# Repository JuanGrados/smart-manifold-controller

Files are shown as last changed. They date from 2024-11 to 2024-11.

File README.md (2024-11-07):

# smart-manifold-controller

__Documentation in progress....__

This is a repository for a smart manifold controller.
It is a porject to control 4 electric water valves and measure the water flow of each of them with water flow sensors.

The project is build around the ESP32-C3-Mini and it is programmed using ESPHome.

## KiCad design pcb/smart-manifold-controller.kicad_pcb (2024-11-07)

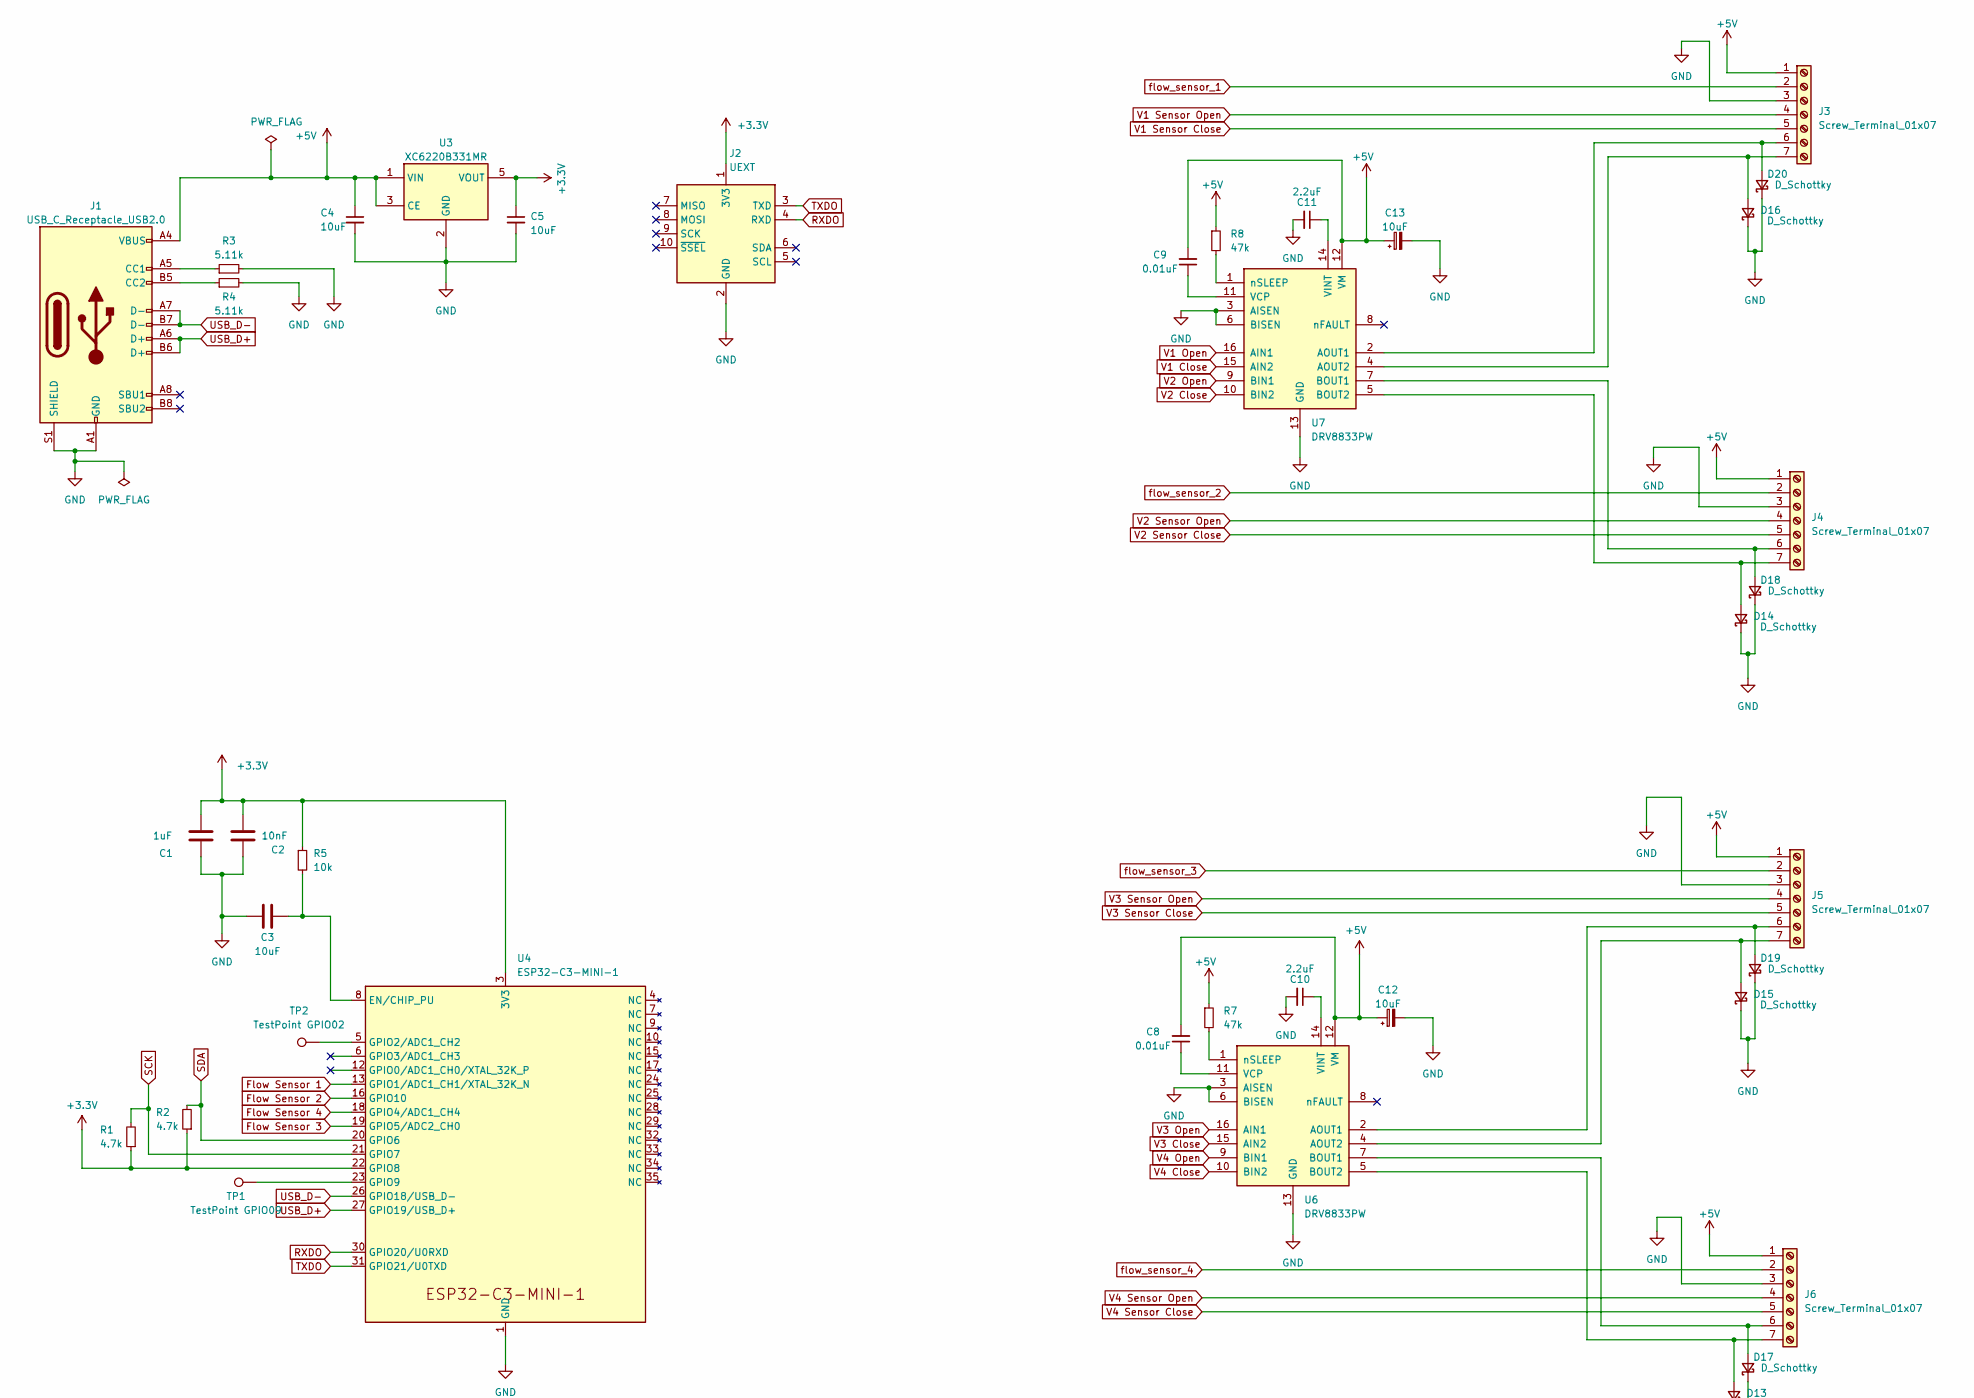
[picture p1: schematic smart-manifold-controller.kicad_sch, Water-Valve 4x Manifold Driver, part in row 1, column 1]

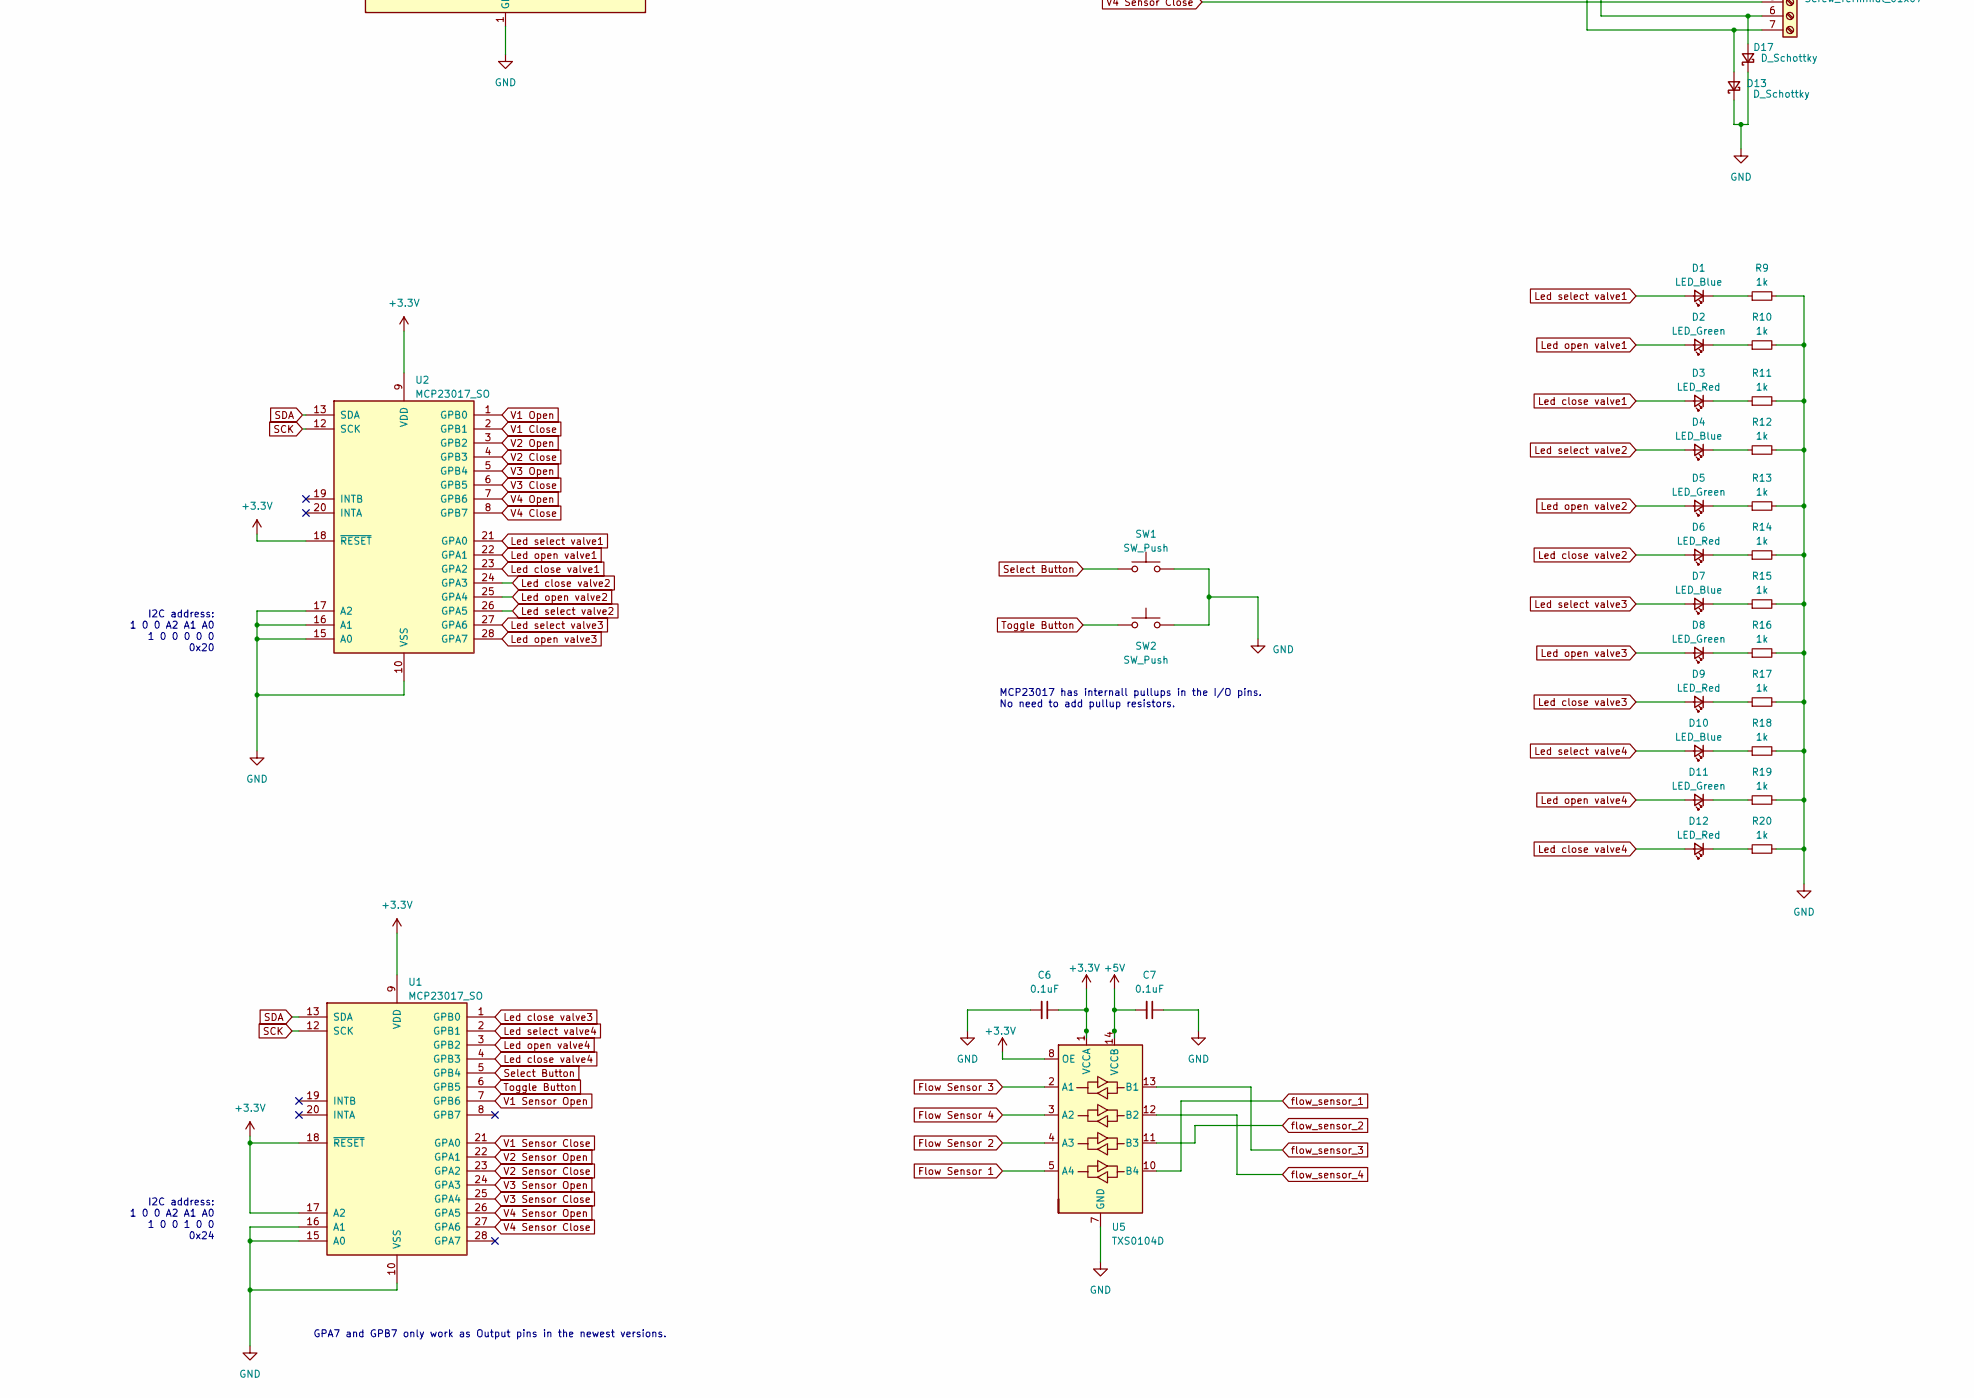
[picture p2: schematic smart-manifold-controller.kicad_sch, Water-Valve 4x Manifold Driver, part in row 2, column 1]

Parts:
C1: 1uF; C_0603_1608Metric
C2: 10nF; C_0603_1608Metric
C3, C4, C5, C12, C13: 10uF; C_0603_1608Metric
C6, C7: 0.1uF; C_0603_1608Metric
C8, C9: 0.01uF; C_0603_1608Metric
C10, C11: 2.2uF; C_0603_1608Metric
D1, D4, D7, D10: LED_Blue; LED_1206_3216Metric
D2, D5, D8, D11: LED_Green; LED_1206_3216Metric
D3, D6, D9, D12: LED_Red; LED_1206_3216Metric
D13, D14, D15, D16, D17, D18, D19, D20: D_Schottky; D_0603_1608Metric
J1: USB_C_Receptacle_USB2.0; USB_C_Receptacle_HRO_TYPE-C-31-M-12
J2: UEXT; JST_EH_S4B-EH_1x04_P2.50mm_Horizontal
J3, J4, J5, J6: Screw_Terminal_01x07; TerminalBlock_Phoenix_MKDS-1,5-7-5.08_1x07_P5.08mm_Horizont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
R1, R2: 4.7k; R_0603_1608Metric
R3, R4: 5.11k; R_0603_1608Metric
R5: 10k; R_0603_1608Metric
R7, R8: 47k; R_0603_1608Metric
R9, R10, R11, R12, R13, R14, R15, R16, R17, R18, R19, R20: 1k; R_0603_1608Metric
SW1, SW2: SW_Push; SW_Push_1P1T_NO_6x6mm_H9.5mm
TP1: TestPoint GPIO09; TestPoint_Pad_D2.0mm
TP2: TestPoint GPIO02; TestPoint_Pad_D2.0mm
U1, U2: MCP23017_SO; SOIC-28W_7.5x17.9mm_P1.27mm
U3: XC6220B331MR; SOT-23-5
U4: ESP32-C3-MINI-1
U5: TXS0104D; SOIC-14_3.9x8.7mm_P1.27mm
U6, U7: DRV8833PW; TSSOP-16_4.4x5mm_P0.65mm

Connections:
+3.3V: C1.1, C2.1, C5.1, C6.1, J2.1 (3V3), R1.1, R2.1, R5.1, U1.9 (VDD), U1.17 (A2), U1.18 (~RESET), U2.9 (VDD), U2.18 (~RESET), U3.5 (VOUT), U4.3 (3V3), U4.22 (GPIO8), U5.1 (VCCA), U5.8 (OE)
+5V: C4.1, C7.2, C8.2, C9.2, C12.1, C13.1, J1.A4 (VBUS), J1.A9 (VBUS), J1.B4 (VBUS), J1.B9 (VBUS), J3.1, J4.1, J5.1, J6.1, R7.1, R8.1, U3.1 (VIN), U3.3 (CE), U5.14 (VCCB), U6.12 (VM), U7.12 (VM)
Flow Sensor 1: U4.13 (GPIO1/ADC1_CH1/XTAL_32K_N), U5.5 (A4)
Flow Sensor 2: U4.16 (GPIO10), U5.4 (A3)
Flow Sensor 3: U4.19 (GPIO5/ADC2_CH0), U5.2 (A1)
Flow Sensor 4: U4.18 (GPIO4/ADC1_CH4), U5.3 (A2)
GND: C1.2, C2.2, C3.1, C4.2, C5.2, C6.2, C7.1, C10.2, C11.2, C12.2, C13.2, D13.1 (K), D14.1 (K), D15.1 (K), D16.1 (K), D17.1 (K), D18.1 (K), D19.1 (K), D20.1 (K), J1.A1 (GND), J1.A12 (GND), J1.B1 (GND), J1.B12 (GND), J1.S1 (SHIELD), J2.2 (GND), J3.3, J4.3, J5.3, J6.3, R3.2, R4.2, R9.2, R10.2, R11.2, R12.2, R13.2, R14.2, R15.2, R16.2, R17.2, R18.2, R19.2, R20.2, SW1.2, SW2.2, U1.10 (VSS), U1.15 (A0), U1.16 (A1), U2.10 (VSS), U2.15 (A0), U2.16 (A1), U2.17 (A2), U3.2 (GND), U4.1 (GND), U4.2 (GND), U4.11 (GND), U4.14 (GND), U4.36 (GND), U4.37 (GND), U4.38 (GND), U4.39 (GND), U4.40 (GND), U4.41 (GND), U4.42 (GND), U4.43 (GND), U4.44 (GND), U4.45 (GND), U4.46 (GND), U4.47 (GND), U4.48 (GND), U4.49 (GND), U4.50 (GND), U4.51 (GND), U4.52 (GND), U4.53 (GND), U5.7 (GND), U6.3 (AISEN), U6.6 (BISEN), U6.13 (GND), U7.3 (AISEN), U7.6 (BISEN), U7.13 (GND)
Led close valve1: D3.2 (A), U2.23 (GPA2)
Led close valve2: D6.2 (A), U2.24 (GPA3)
Led close valve3: D9.2 (A), U1.1 (GPB0)
Led close valve4: D12.2 (A), U1.4 (GPB3)
Led open valve1: D2.2 (A), U2.22 (GPA1)
Led open valve2: D5.2 (A), U2.25 (GPA4)
Led open valve3: D8.2 (A), U2.28 (GPA7)
Led open valve4: D11.2 (A), U1.3 (GPB2)
Led select valve1: D1.2 (A), U2.21 (GPA0)
Led select valve2: D4.2 (A), U2.26 (GPA5)
Led select valve3: D7.2 (A), U2.27 (GPA6)
Led select valve4: D10.2 (A), U1.2 (GPB1)
unnamed: D1.1 (K), R9.1
unnamed: D2.1 (K), R10.1
unnamed: D3.1 (K), R11.1
unnamed: D4.1 (K), R12.1
unnamed: D5.1 (K), R13.1
unnamed: D6.1 (K), R14.1
unnamed: D7.1 (K), R15.1
unnamed: D8.1 (K), R16.1
unnamed: D9.1 (K), R17.1
unnamed: D10.1 (K), R18.1
unnamed: D11.1 (K), R19.1
unnamed: D12.1 (K), R20.1
unnamed: D13.2 (A), J6.7, U6.5 (BOUT2)
unnamed: D14.2 (A), J4.7, U7.5 (BOUT2)
unnamed: D15.2 (A), J5.7, U6.4 (AOUT2)
unnamed: D16.2 (A), J3.7, U7.4 (AOUT2)
unnamed: D17.2 (A), J6.6, U6.7 (BOUT1)
unnamed: D18.2 (A), J4.6, U7.7 (BOUT1)
unnamed: D19.2 (A), J5.6, U6.2 (AOUT1)
unnamed: D20.2 (A), J3.6, U7.2 (AOUT1)
unnamed: J1.A5 (CC1), R3.1
unnamed: J1.B5 (CC2), R4.1
unnamed: C3.2, R5.2, U4.8 (EN/CHIP_PU)
unnamed: TP2.1, U4.5 (GPIO2/ADC1_CH2)
unnamed: TP1.1, U4.23 (GPIO9)
unnamed: C8.1, U6.11 (VCP)
unnamed: C10.1, U6.14 (VINT)
unnamed: R7.2, U6.1 (nSLEEP)
unnamed: C9.1, U7.11 (VCP)
unnamed: C11.1, U7.14 (VINT)
unnamed: R8.2, U7.1 (nSLEEP)
RXDO: J2.4 (RXD), U4.30 (GPIO20/U0RXD)
SCK: R1.2, U1.12 (SCK), U2.12 (SCK), U4.21 (GPIO7)
SDA: R2.2, U1.13 (SDA), U2.13 (SDA), U4.20 (GPIO6)
Select Button: SW1.1, U1.5 (GPB4)
TXDO: J2.3 (TXD), U4.31 (GPIO21/U0TXD)
Toggle Button: SW2.1, U1.6 (GPB5)
USB_D+: J1.A6 (D+), J1.B6 (D+), U4.27 (GPIO19/USB_D+)
USB_D-: J1.A7 (D-), J1.B7 (D-), U4.26 (GPIO18/USB_D-)
V1 Close: U2.2 (GPB1), U7.15 (AIN2)
V1 Open: U2.1 (GPB0), U7.16 (AIN1)
V1 Sensor Close: J3.5, U1.21 (GPA0)
V1 Sensor Open: J3.4, U1.7 (GPB6)
V2 Close: U2.4 (GPB3), U7.10 (BIN2)
V2 Open: U2.3 (GPB2), U7.9 (BIN1)
V2 Sensor Close: J4.5, U1.23 (GPA2)
V2 Sensor Open: J4.4, U1.22 (GPA1)
V3 Close: U2.6 (GPB5), U6.15 (AIN2)
V3 Open: U2.5 (GPB4), U6.16 (AIN1)
V3 Sensor Close: J5.5, U1.25 (GPA4)
V3 Sensor Open: J5.4, U1.24 (GPA3)
V4 Close: U2.8 (GPB7), U6.10 (BIN2)
V4 Open: U2.7 (GPB6), U6.9 (BIN1)
V4 Sensor Close: J6.5, U1.27 (GPA6)
V4 Sensor Open: J6.4, U1.26 (GPA5)
flow_sensor_1: J3.2, U5.10 (B4)
flow_sensor_2: J4.2, U5.11 (B3)
flow_sensor_3: J5.2, U5.13 (B1)
flow_sensor_4: J6.2, U5.12 (B2)

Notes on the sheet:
GPA7 and GPB7 only work as Output pins in the newest versions.
I2C address: 1 0 0 A2 A1 A0 1 0 0 0 0 0 0x20
I2C address: 1 0 0 A2 A1 A0 1 0 0 1 0 0 0x24
MCP23017 has internall pullups in the I/O pins. No need to add pullup resistors.

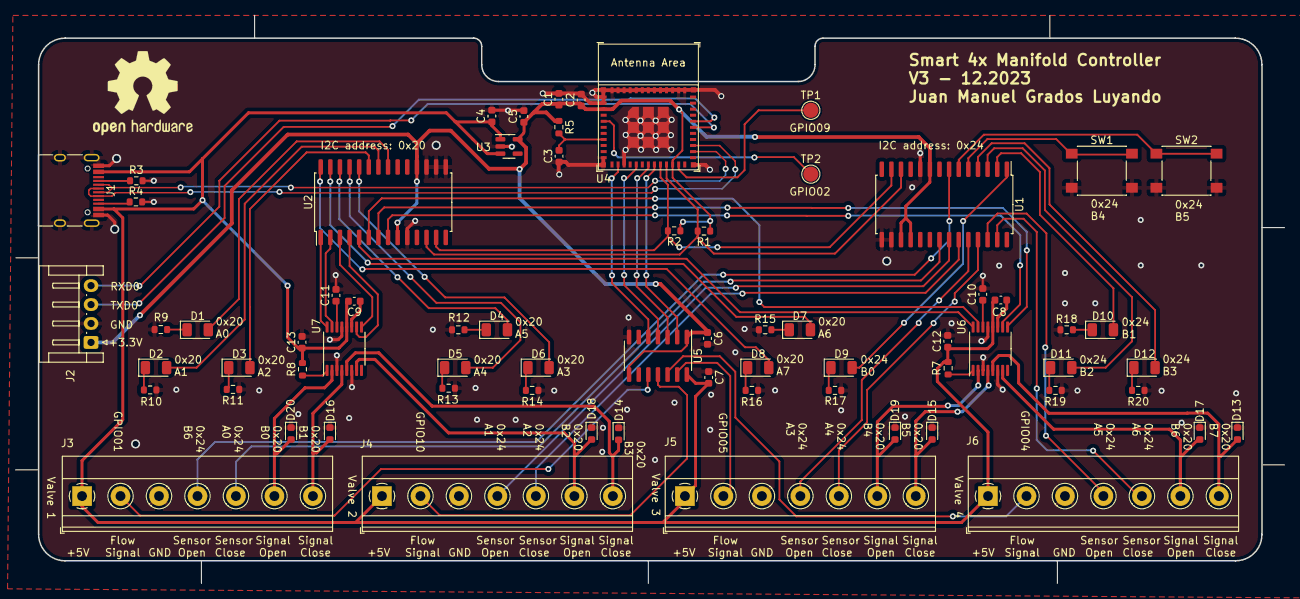
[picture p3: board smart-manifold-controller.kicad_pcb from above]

Board: 2 copper layers, 167.6 x 75.0 mm, 69 parts (0 on the bottom side), 78 nets.

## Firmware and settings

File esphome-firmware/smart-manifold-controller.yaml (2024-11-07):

esphome:
  name: smart-manifold-controller
  friendly_name: smart-manifold-controller

esp32:
  board: esp32-c3-devkitm-1
  framework:
    type: arduino

# Enable logging
logger:

# Enable Home Assistant API
api:
  encryption:
    key: 

ota:
  platform: esphome  
  password: 

wifi:
  ssid: !secret wifi_ssid
  password: !secret wifi_password

  # Enable fallback hotspot (captive portal) in case wifi connection fails
  ap:
    ssid: "smart-manifold-controller"
    password: "appassword"

captive_portal:
    


i2c:
  sda: 6
  scl: 7
  scan: true
  id: bus_a
  frequency: 100kHz

# GPIO expander
mcp23017:
  - id: 'mcp23017_hub_1'
    address: 0x20
  - id: 'mcp23017_hub_2'
    address: 0x24

switch:
# Valve 1
  - platform: gpio
    internal: true 
    id: "valve_1_open_pin"
    pin:
      mcp23xxx: mcp23017_hub_1
      number: 8 # Use pin 1-B0
      mode:
        output: true
  - platform: gpio
    internal: true
    id: "valve_1_close_pin"
    pin:
      mcp23xxx: mcp23017_hub_1
      number: 9 # Use pin 1-B1
      mode:
        output: true
  - platform: gpio
    internal: true
    id: "valve_1_select_led"
    pin:
      mcp23xxx: mcp23017_hub_1
      number: 0 # Use pin 1-A0
      mode:
        output: true
      inverted: false
  - platform: gpio
    internal: true
    id: "valve_1_on_led"
    pin:
      mcp23xxx: mcp23017_hub_1
      number: 1 # Use pin 1-A1
      mode:
        output: true
      inverted: false
  - platform: gpio
    internal: true
    id: "valve_1_off_led"
    pin:
      mcp23xxx: mcp23017_hub_1
      number: 2 # Use pin 1-A2
      mode:
        output: true
      inverted: false

# Valve 2
  - platform: gpio
    internal: true 
    id: "valve_2_open_pin"
    pin:
      mcp23xxx: mcp23017_hub_1
      number: 10 # Use pin 1-B2
      mode:
        output: true
  - platform: gpio
    internal: true
    id: "valve_2_close_pin"
    pin:
      mcp23xxx: mcp23017_hub_1
      number: 11 # Use pin 1-B3
      mode:
        output: true
  - platform: gpio
    internal: true
    id: "valve_2_select_led"
    pin:
      mcp23xxx: mcp23017_hub_1
      number: 5 # Use pin 1-A5
      mode:
        output: true
      inverted: false
  - platform: gpio
    internal: true
    id: "valve_2_on_led"
    pin:
      mcp23xxx: mcp23017_hub_1
      number: 4 # Use pin 1-A4
      mode:
        output: true
      inverted: false
  - platform: gpio
    internal: true
    id: "valve_2_off_led"
    pin:
      mcp23xxx: mcp23017_hub_1
      number: 3 # Use pin 1-A53/
      mode:
        output: true
      inverted: false

# Valve 3
  - platform: gpio
    internal: true 
    id: "valve_3_open_pin"
    pin:
      mcp23xxx: mcp23017_hub_1
      number: 12 # Use pin 1-B4
      mode:
        output: true
  - platform: gpio
    internal: true
    id: "valve_3_close_pin"
    pin:
      mcp23xxx: mcp23017_hub_1
      number: 13 # Use pin 1-B5
      mode:
        output: true
  - platform: gpio
    internal: true
    id: "valve_3_select_led"
    pin:
      mcp23xxx: mcp23017_hub_1
      number: 6 # Use pin 1-A6
      mode:
        output: true
      inverted: false
  - platform: gpio
    internal: true
    id: "valve_3_on_led"
    pin:
      mcp23xxx: mcp23017_hub_1
      number: 7 # Use pin 1-A7
      mode:
        output: true
      inverted: false    
  - platform: gpio
    internal: true
    id: "valve_3_off_led"
    pin:
      mcp23xxx: mcp23017_hub_2
      number: 8 # Use pin 2-B0
      mode:
        output: true
      inverted: false  

# Valve 4
  - platform: gpio
    internal: true 
    id: "valve_4_open_pin"
    pin:
      mcp23xxx: mcp23017_hub_1
      number: 14 # Use pin 1-B6
      mode:
        output: true
  - platform: gpio
    internal: true
    id: "valve_4_close_pin"
    pin:
      mcp23xxx: mcp23017_hub_1
      number: 15 # Use pin 1-B7
      mode:
        output: true
  - platform: gpio
    internal: true
    id: "valve_4_select_led"
    pin:
      mcp23xxx: mcp23017_hub_2
      number: 9 # Use pin 2-B1
      mode:
        output: true
      inverted: false
  - platform: gpio
    internal: true
    id: "valve_4_on_led"
    pin:
      mcp23xxx: mcp23017_hub_2
      number: 10 # Use pin 2-B2
      mode:
        output: true
      inverted: false     
  - platform: gpio
    internal: true
    id: "valve_4_off_led"
    pin:
      mcp23xxx: mcp23017_hub_2
      number: 11 # Use pin 2-B3
      mode:
        output: true
      inverted: false          

# Template switches putting together the open, close and state signals for each valve
# Valve 1
  - platform: template
    name: "Valve 1 Switch"
    id: "valve_1_switch"
    lambda: |-
      if (id(valve_1_open_signal).state) {
        return true;
      } else {
        return false;
      }
    turn_on_action:
      - switch.turn_on: valve_1_open_pin
      - switch.turn_off: valve_1_close_pin
    turn_off_action:
      - switch.turn_off: valve_1_open_pin
      - switch.turn_on: valve_1_close_pin
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

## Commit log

2024-11-07 Add files via upload
    PCB files
    [smart-manifold-controller.kicad_pcb, smart-manifold-controller.kicad_sch]
2024-11-07 Add files via upload
    esphome firmware
    [smart-manifold-controller.yaml]
